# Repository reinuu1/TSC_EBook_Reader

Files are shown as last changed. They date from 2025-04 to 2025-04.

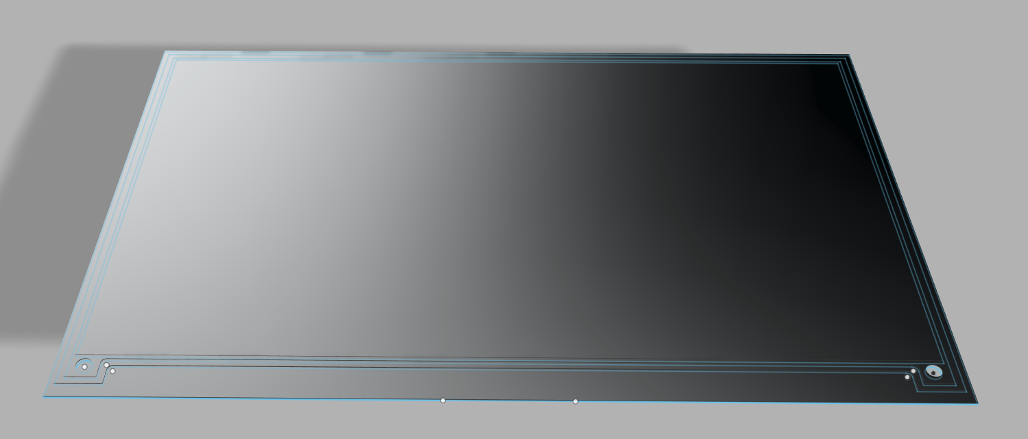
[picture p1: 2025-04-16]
Images/Display.png

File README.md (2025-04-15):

# 📘 TSC_EBook_Reader

## 👨‍💻 Proiect realizat de: DINU Andrei-Marian  
### 📚 Pentru cursul: Teoria Sistemelor de Calcul, 2025  

---

## 🔍 Descriere generală

**OpenBook** este un e-reader open-source, construit în jurul microcontrollerului **ESP32-C6**.  
Acesta dispune de:

- Display **E-Ink 7.5"**
- Baterie **Li-Po**
- Stocare **microSD**
- Senzori de mediu (**BME688**)
- Modul RTC (**DS3231**)

---



## Mapping pini ESP32-C6

| Semnal | ESP32 Pin | Funcție |
|---|---|---|
| EPD_BUSY | IO3 | Status display |
| EPD_RST | IO23 | Reset display |
| EPD_DC | IO5 | Data/Command |
| EPD_CS | IO10 | SPI CS pentru e-paper |
| EPD_CLK | IO6 | SPI Clock |
| EPD_MOSI | IO7 | SPI Data Out |
| SS_SD | IO4 | SD Card CS |
| SD_MISO | IO2 | SPI MISO |
| I2C_SDA | IO21 | RTC + BME688 |
| I2C_SCL | IO22 | RTC + BME688 |
| RTC_RST | IO18 | Reset DS3231 |
| RTC_INT | IO0 | Interrupt RTC |
| 32KHz_CLK | IO1 | Oscilator RTC |
| IO/BOOT Btn | IO9 | Boot |
| IO/CHANGE Btn | IO15 | Navigare |
| RESET | EN | Reset MCU |

## Microcontroller: ESP32-C6-WROOM-1

- **Arhitectură:** RISC-V 32-bit @ 160 MHz  
- **Memorie:** 320KB ROM, 512KB SRAM  
- **Conectivitate:** Wi-Fi 6 (2.4GHz), Bluetooth 5.0  
- **Consum:** ~10mA activ, ~160μA deep sleep  

**Interfețe utilizate:**
- **SPI** – e-paper, microSD, memorie Flash
- **I2C** – RTC, senzor de mediu
- **GPIO** – butoane, LED, semnale control

## 🖥️ Display: Waveshare 7.5" e-Ink V2

- **Rezoluție:** 800x480 px  
- **Interfață:** SPI  
- **Consum:** ~1.2mW activ, ~0.1mW standby

## 🔋 Alimentare

- **Baterie:** Li-Po 1800–2500mAh  
- **Încărcător:** MCP73831  
- **Regulator:** XC6221 LDO 3.3V  

**Protecții integrate:**

- Diodă Schottky – polaritate inversă  
- Varistor ESD – protecție USB  
- Supercapacitor – buffering boot/flash  

**Conectare la ESP32-C6:**

IO7 → MOSI
IO6 → SCK
IO10 → CS
IO5 → DC
IO23 → RST
IO3 → BUSY

## Stocare: MicroSD + SPI Flash
### microSD (până la 32GB FAT32)

IO4 → CS_SD
IO2 → MISO
IO7 → MOSI (partajat)
IO6 → SCK (partajat)
Flash SPI externă (Winbond W25Q64JV – 64Mb)
IO11 → CS
IO2, IO6, IO7 partajați

##  Senzor Mediu: Bosch BME688
- Măsoară: temperatură, umiditate, presiune, compuși gazoși  
- **Consum:** ~3.6mA activ, ~0.1μA sleep  
- **Interfață:** I2C  

**Conectare:**

IO21 → SDA
IO22 → SCL
IO19 → VDDIO (enable senzor)

## RTC: DS3231

- **Precizie:** ±2ppm, compensat termic  
- **Backup:** funcționează pe baterie  
- **Consum:** ~1.5μA backup, ~0.1μA sleep 

**Conectare:**

IO21 → SDA
IO22 → SCL
IO18 → RST
IO0 → INT/SQW
IO1 → 32KHz Clock Out

## ⚡ Estimare consum

| Modul | Activ (mA) | Sleep (μA) |
|---|---|---|
| ESP32-C6 | ~10 | ~160 |
| Display | ~1.2 | ~0.1 |
| microSD | ~50 | ~10 |
| BME688 | ~3.6 | ~0.1 |
| RTC | ~0.0015 | ~0.0001 |
| **Total** | **~65mA**  | **~170μA** |

## Interfață utilizator
- 3 Butoane tactile (TS-1187A):

IO9 → BOOT
IO15 → CHANGE
EN → RESET

- LED status: GPIO + rezistor pull-down  
- Feedback: control simplu via GPIO 

## Alte componente

- **Conector FPC:** Hirose FH34SRJ-24S  
- **Test Pads:** silkscreen pentru depanare  
- **Qwiic/I²C Header:** pentru extensii viitoare 

Observații finale
Toate comunicațiile SPI sunt partajate pe același bus, controlate prin CS separat.

Designul este gândit pentru eficiență energetică și poate funcționa zeci de ore în standby.

Tot sistemul este gândit pentru a fi reproductibil și open-source, ușor de extins cu alte module I²C sau SPI

##  Design Decizii & Trade-offs

-  Alegere ESP32-C6: conectivitate & suport FreeRTOS  
-  E-paper pentru consum redus  
-  Un singur bus SPI (cu CS dedicat pentru SD și e-paper)  
-  GPIO-uri simple pentru butoane

## Debug & Testare

-  Verificare DRC (JLCPCB .dru)  
-  Alimentare testată cu Li-Po + charging  
-  Interfețe SPI & I2C testate cu logic analyzer  
-  Consumul în deep sleep confirmat < 200μA

##  Datasheet-uri & Linkuri componente

| Componentă | Link Datasheet | LINK |
|---|---|---|
| USB Connector 112A-TAAR-R03 | [ESP32-C6-WROOM-1](https://www.attend.com.tw/data/download/file/112A-TAAR-R03_Spec.pdf) | [Status display](https://www.digikey.com/en/products/detail/attend-technology/112A-TAAR-R03/17633923) |
| Inductor 68uH (Würth) | [7.5" V2 e-Paper](https://www.we-online.com/components/products/datasheet/784373170680.pdf) | [Reset display ](https://eu.mouser.com/ProductDetail/Wurth-Elektronik/784373170680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) |
| LED Bridgelux | [DS3231](https://www.bridgelux.com/sites/default/files/resource_media/DS51_Rev%20F%20Bridgelux%20SMD%203030%20Data%20sheet.pdf)  | [Data/Command](https://www.digikey.com/en/products/detail/bridgelux/BXEM-27E0000-0-000/6618599) |
| Voltage Detector BD5229G | [BME688 ](https://fscdn.rohm.com/en/products/databook/datasheet/ic/power/voltage_detector/bd52xxg-e.pdf) | [SPI CS pentru e-paper ](https://www.digikey.com/en/products/detail/rohm-semiconductor/BD5229G-TR/658502) |
| Butoane TL3315 | [XC6221B331MR-G](https://fscdn.rohm.com/en/products/databook/datasheet/ic/power/voltage_detector/bd52xxg-e.pdf) | [SPI Clock ](https://www.digikey.com/en/products/detail/rohm-semiconductor/BD5229G-TR/658502) |
| Supercapacitor 0.011F 3.3V | [MCP73831T-2ACI/OT ](https://mm.digikey.com/Volume0/opasdata/d220001/medias/docus/6537/rev05-CPHCPM.pdf) | [SPI Data Out ](https://www.digikey.com/en/products/detail/seiko-instruments/cph3225a/8692444) |
| RTC DS3231SN | [LP584174 (1800mAh) ](https://www.analog.com/media/en/technical-documentation/data-sheets/DS3231.pdf) | [SD Card CS ](https://www.digikey.com/en/products/detail/analog-devices-inc-maxim-integrated/DS3231SN/1197576) |
| Capacitor 0402YD104MAT2A | [FH34SRJ-24S-0.5SH(50)](https://eu.mouser.com/datasheet/2/40/cx5r_KGM-3223198.pdf) | [SPI MISO ](https://eu.mouser.com/ProductDetail/KYOCERA-AVX/0402YD104MAT2A?qs=4PckX6MNpMErOINbbZj3Cw%3D%3D) |
| ESP32-C6-WROOM-1-N8 | [W25Q64JV ](https://www.espressif.com/sites/default/files/documentation/esp32-c6-wroom-1_wroom-1u_datasheet_en.pdf)  | [RTC + BME688 ](https://www.digikey.com/en/products/detail/espressif-systems/ESP32-C6-WROOM-1-N8/17728866) |
| Varistor USB PFMF.050.2 | [Molex 104031-0811 ](https://ro.mouser.com/datasheet/2/358/typ_PFMF-1275918.pdf) | [RTC + BME688 ](https://ro.mouser.com/ProductDetail/Schurter/PFMF.050.2?qs=1auRipcfynCums5v1iucSA%3D%3D) |
| DiodA Schottky SD0805S020S1R0 | [USB4110-GF-A ](https://datasheets.kyocera-avx.com/schottky.pdf) | [Reset DS3231 ](https://www.digikey.com/en/products/detail/kyocera-avx/sd0805s020s1r0/3749517) |
| Senzor BME680 | [SS14 ](https://www.bosch-sensortec.com/media/boschsensortec/downloads/datasheets/bst-bme680-ds001.pdf) | [ Interrupt RTC  ](https://www.digikey.com/en/products/detail/bosch-sensortec/bme680/7401317) |
| Rezistori SMD 0402 | [PFMF05S050T2 ](https://www.yageo.com/upload/media/product/products/datasheet/rchip/PYu-RC_Group_51_RoHS_L_12.pdf) | [Oscilator RTC ](https://www.digikey.com/en/products/detail/yageo/RC0402JR-07100KL/726416) |
| P-MOS DMG2305UX-7 | [TS-1187A-B-A-B ](https://www.diodes.com/assets/Datasheets/DMG2305UX.pdf) | [Boot ](https://www.digikey.com/en/products/detail/diodes-incorporated/DMG2305UX-7/4340667) |
| MCP73831T (Charger IC) | [RC0402FR-07100KL ](https://ww1.microchip.com/downloads/en/DeviceDoc/MCP73831-Family-Data-Sheet-DS20001984H.pdf) | [Navigare ](https://www.digikey.com/en/products/detail/microchip-technology/MCP73831T-2ACI-OT/964301) |
| Hirose FH34SRJ-24S-0.5SH | [GRM155R61A105KE15D ](https://ro.mouser.com/datasheet/2/185/FH34SRJ_24S_0_5SH_99__CL0580_1255_6_99_2DDrawing_0-1615044.pdf)| [Reset MCU ](https://ro.mouser.com/ProductDetail/Hirose-Connector/FH34SRJ-24S-0.5SH99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) |
| Battery Monitor MAX17048 | https://www.analog.com/media/en/technical-documentation/data-sheets/max17048-max17049.pdf | https://www.digikey.com/en/products/detail/analog-devices-inc-maxim-integrated/MAX17048G-T10/3758921 |
| Diodă MBR0530 | https://ro.mouser.com/datasheet/2/258/MBR0520_MBR0580_SOD123_-2492194.pdf | https://ro.mouser.com/ProductDetail/Micro-Commercial-Components-MCC/MBR0530-TP?qs=KFo7JewZbUECRHkxGanrdg%3D%3D |
| ESD Suppressor – PGB1010603MR | https://www.littelfuse.com/assetdocs/pulseguard-esd-suppressors-pgb1-datasheet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 | https://www.digikey.com/en/products/detail/littelfuse-inc/PGB1010603MR/715755 |
| Qwiic Connector OM-E-QWIIC | https://www.sparkfun.com/qwiic | https://www.digikey.com/en/products/detail/onion-corporation/om-e-qwiic/9922970 |
| Capacitor 0.5pF–100uF GCQ1555C1HR50WB01 | https://ro.mouser.com/datasheet/2/281/1/GCQ1555C1HR50WB01_01A-3146956.pdf | https://ro.mouser.com/ProductDetail/Murata-Electronics/GCQ1555C1HR50WB01D?qs=0lQeLiL1qybSG%2FOlONlvIA%3D%3D |
| USB-C Conector USB4110-GF-A | https://gct.co/files/drawings/usb4110.pdf | https://eu.mouser.com/ProductDetail/GCT/USB4110-GF-A?qs=KUoIvG%2F9IlYiZvIXQjyJeA%3D%3D |
| Rezistor | https://industrial.panasonic.com/ww/products/pt/general-purpose-chip-resistors/models/ERJ2GE0R00X | https://www.digikey.com/en/products/detail/panasonic-electronic-components/ERJ-2GE0R00X/146727 |

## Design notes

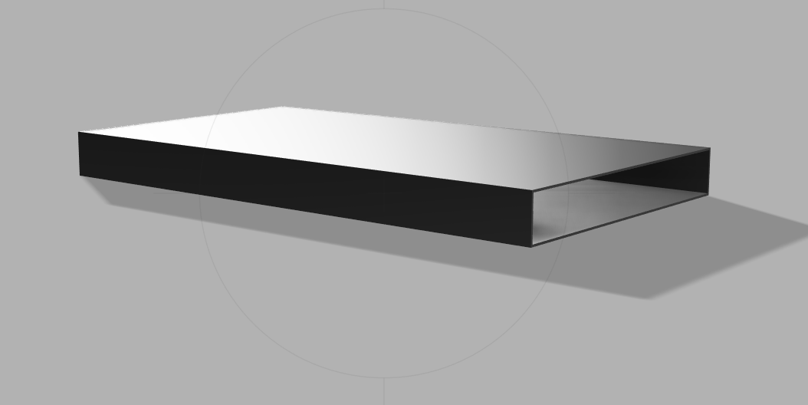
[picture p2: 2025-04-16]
Images/Battery.png

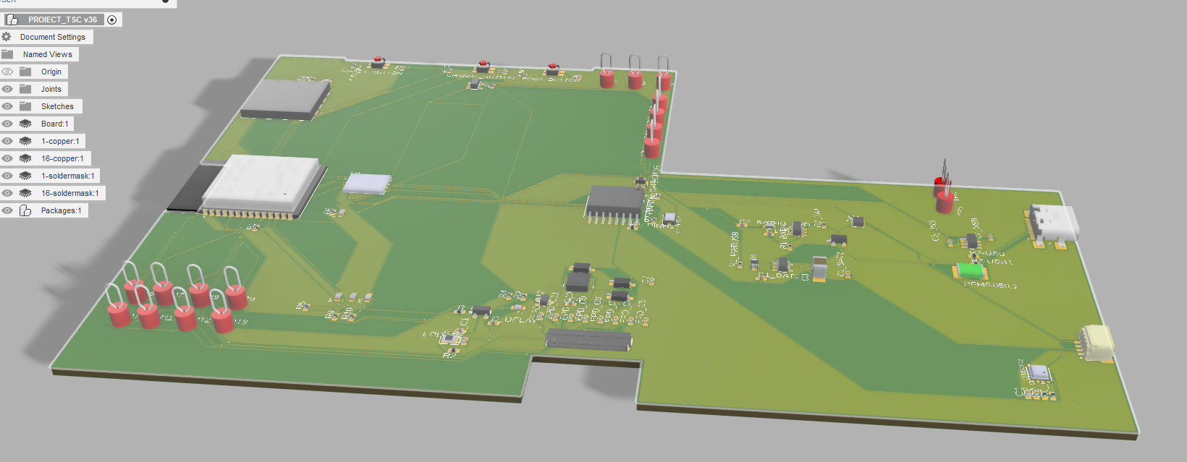
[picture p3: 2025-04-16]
Images/PCB.png

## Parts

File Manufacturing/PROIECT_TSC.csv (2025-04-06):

Qty | Value | Device | Package | Parts | Description | ARROW_PART_NUMBER | ARROW_PRICE-STOCK | AVAILABILITY | CENTROID_NOT_SPECIFIED | CHECK_PRICES | COPYRIGHT | DATASHEET | DESCRIPTION | DIGIKEY_DESCRIPTION | DIGIKEY_PART_NUMBER | HEIGHT | LEAD_FREE | MANUFACTURER_NAME | MANUFACTURER_PART_NUMBER | MF | MFR_NAME | MOUSER_PART_NUMBER | MOUSER_PRICE-STOCK | MOUSER_TESTING_PART_NUMBER | MOUSER_TESTING_PRICE-STOCK | MP | MPN | PACKAGE | POPULARITY | PREFIX | PRICE | PROD_ID | PURCHASE-URL | ROHS | SNAPEDA_LINK | SPICEMODEL | SPICEPREFIX | TEMPERATURE_RANGE_HIGH | TEMPERATURE_RANGE_LOW | TP_SIGNAL_NAME | VALUE
1 |  | ADAFRUIT_LEDCHIP-LED0603 | ADAFRUIT_CHIP-LED0603 | CHG_LED | LED
3 |  | BUTTON_CUSYOMV1 | MYBUTTON | BOOT_BUTTON, CHANGE_BUTTON, RESET_BUTTON
1 |  | ESP32C6_VARISTORCN1812 | ESP32C6_VARISTOR_CT/CN1812 | PFMF.050.1 | VARISTOR |  |  |  |  |  |  |  |  |  |  |  |  |  |  |  |  |  |  |  |  |  |  |  | 0
1 |  | ESP32_WROVER_SPARKFUN-IC-POWER_MCP73831 | ESP32_WROVER_SPARKFUN-IC-POWER_SOT23-5 | MCP73831 | MCP73831T Li-Ion, Li-Pol Controller |  |  |  |  |  |  |  |  |  |  |  |  |  |  |  |  |  |  |  |  |  |  |  |  |  |  | IC-09995
1 |  | SJ | SJ | SJ1 | SMD solder JUMPER |  |  |  |  |  |  |  |  |  |  |  |  |  |  |  |  |  |  |  |  |  |  |  | 3
10 | 0.1uF/50V | EAGLE-LTSPICE_CC0402 | EAGLE-LTSPICE_C0402 | EPD_C1, EPD_C2, EPD_C5, EPD_C6, EPD_C7, EPD_C8, EPD_C9, EPD_C10, EPD_C11, EPD_C12 | CAPACITOR, European symbol |  |  |  |  |  |  |  |  |  |  |  |  |  |  |  |  |  |  |  |  |  |  |  |  |  |  |  |  |  |  | NONE | C
1 | 0.47 | ESP32_WROVER_EAGLE-LTSPICE_RR0402 | ESP32_WROVER_EAGLE-LTSPICE_R0402 | R3 | RESISTOR, European symbol |  |  |  |  |  |  |  |  |  |  |  |  |  |  |  |  |  |  |  |  |  |  |  |  |  |  |  |  |  |  | NONE | R
1 | 100K | ESP32_WROVER_EAGLE-LTSPICE_RR0402 | ESP32_WROVER_EAGLE-LTSPICE_R0402 | R1_PWRUSB | RESISTOR, European symbol |  |  |  |  |  |  |  |  |  |  |  |  |  |  |  |  |  |  |  |  |  |  |  |  |  |  |  |  |  |  | NONE | R
7 | 100nF | EAGLE-LTSPICE_CC0402 | EAGLE-LTSPICE_C0402 | C1, C2, C4_USB, C6, C8, C10, C_DELAY | CAPACITOR, European symbol |  |  |  |  |  |  |  |  |  |  |  |  |  |  |  |  |  |  |  |  |  |  |  |  |  |  |  |  |  |  | NONE | C
1 | 100uF | EAGLE-LTSPICE_CC0402 | EAGLE-LTSPICE_C0402 | C9 | CAPACITOR, European symbol |  |  |  |  |  |  |  |  |  |  |  |  |  |  |  |  |  |  |  |  |  |  |  |  |  |  |  |  |  |  | NONE | C
1 | 100uF TANT | RCL_CPOL-EUCT3528 | RCL_CT3528 | C3 | POLARIZED CAPACITOR, European symbol |  |  |  |  |  |  |  |  |  |  |  |  |  |  |  |  |  |  |  |  |  |  |  | 0 |  |  |  |  |  |  |  | C
16 | 10K | ESP32_WROVER_EAGLE-LTSPICE_RR0402 | ESP32_WROVER_EAGLE-LTSPICE_R0402 | R1, R1_PINH, R1_PINH1, R2-PINH, R2-PINH1, R4, R5, R6, R7, R8, R9, R10, R_BOOT, R_CHANGE, R_CL1, R_RESET | RESISTOR, European symbol |  |  |  |  |  |  |  |  |  |  |  |  |  |  |  |  |  |  |  |  |  |  |  |  |  |  |  |  |  |  | NONE | R
1 | 10uF | EAGLE-LTSPICE_CC0402 | EAGLE-LTSPICE_C0402 | C7 | CAPACITOR, European symbol |  |  |  |  |  |  |  |  |  |  |  |  |  |  |  |  |  |  |  |  |  |  |  |  |  |  |  |  |  |  | NONE | C
1 | 112A-TAAR-R03_ATTEND | 112A-TAAR-R03_ATTEND | 112ATAARR03ATTEND | J4 | Micro SD Card Socket, Push-Push Type, Top Mount, SMT, H=1.83mm, 10u |  |  |  |  |  |  |  | Micro SD Card Socket | Push-Push Type | Top Mount | SMT | H=1.83mm | 10u |  |  | 1.9mm |  | ATTEND | 112A-TAAR-R03 ATTEND
1 | 15 | ESP32_WROVER_EAGLE-LTSPICE_RR0402 | ESP32_WROVER_EAGLE-LTSPICE_R0402 | R_CAPACITOR | RESISTOR, European symbol |  |  |  |  |  |  |  |  |  |  |  |  |  |  |  |  |  |  |  |  |  |  |  |  |  |  |  |  |  |  | NONE | R
1 | 1uF | EAGLE-LTSPICE_CC0402 | EAGLE-LTSPICE_C0402 | C5 | CAPACITOR, European symbol |  |  |  |  |  |  |  |  |  |  |  |  |  |  |  |  |  |  |  |  |  |  |  |  |  |  |  |  |  |  | NONE | C
1 | 2.2 | ESP32_WROVER_EAGLE-LTSPICE_RR0402 | ESP32_WROVER_EAGLE-LTSPICE_R0402 | R2 | RESISTOR, European symbol |  |  |  |  |  |  |  |  |  |  |  |  |  |  |  |  |  |  |  |  |  |  |  |  |  |  |  |  |  |  | NONE | R
1 | 200 | ESP32_WROVER_EAGLE-LTSPICE_RR0402 | ESP32_WROVER_EAGLE-LTSPICE_R0402 | R1_BAT | RESISTOR, European symbol |  |  |  |  |  |  |  |  |  |  |  |  |  |  |  |  |  |  |  |  |  |  |  |  |  |  |  |  |  |  | NONE | R
2 | 20V/4.2A/52mO/1.4W | ESP32_WROVER_SPARKFUN-DISCRETESEMI_MOSFET_PCH-DMG2305UX-7 | ESP32_WROVER_SPARKFUN-DISCRETESEMI_SOT23-3 | Q1, Q2 | P-channel MOSFETs |  |  |  |  |  |  |  |  |  |  |  |  |  |  |  |  |  |  |  |  |  |  |  |  |  |  | TRAN-14388 |  |  |  |  |  |  |  |  | 20V/4.2A/52mO/1.4W
1 | 2K | ESP32_WROVER_EAGLE-LTSPICE_RR0402 | ESP32_WROVER_EAGLE-LTSPICE_R0402 | R2_BAT | RESISTOR, European symbol |  |  |  |  |  |  |  |  |  |  |  |  |  |  |  |  |  |  |  |  |  |  |  |  |  |  |  |  |  |  | NONE | R
5 | 4.7uF | EAGLE-LTSPICE_CC0402 | EAGLE-LTSPICE_C0402 | C1_BAT, C1_BAT1, C1_BAT2, C2_BAT, C5_USB | CAPACITOR, European symbol |  |  |  |  |  |  |  |  |  |  |  |  |  |  |  |  |  |  |  |  |  |  |  |  |  |  |  |  |  |  | NONE | C
1 | 4.7uF/25V | EAGLE-LTSPICE_CC0402 | EAGLE-LTSPICE_C0402 | C4 | CAPACITOR, European symbol |  |  |  |  |  |  |  |  |  |  |  |  |  |  |  |  |  |  |  |  |  |  |  |  |  |  |  |  |  |  | NONE | C
2 | 5k1 | ESP32_WROVER_EAGLE-LTSPICE_RR0402 | ESP32_WROVER_EAGLE-LTSPICE_R0402 | R2-USB, R2-USB1 | RESISTOR, European symbol |  |  |  |  |  |  |  |  |  |  |  |  |  |  |  |  |  |  |  |  |  |  |  |  |  |  |  |  |  |  | NONE | R
1 | 68uH | 744043680IND_4828-WE-TPC_WRE | IND_4828-WE-TPC_WRE | L1 |  |  |  |  |  |  | Copyright (C) 2024 Ultra Librarian. All rights reserved. |  |  |  |  |  |  |  | 744043680 |  | Wurth Electronics
1 | BD5229G-TR | BD5229G-TR | SOT95P280X125-5N | IC1 | Voltage Detector with Adjustable Delay Time: CMOS processes are utilized to develop high precision, low current consumption CMOS reset ICs that allow arbitrary setting of the delay time. The extensive lineup includes both Nch Open Drain and CMOS output types in a wide range of detection voltages (from 2.3V to 6.0V, in 0.1V steps), enabling selection of the ideal solution based on customer requirements. In addition, the entire series is of course both lead-free and RoHS-compliant. |  |  |  |  |  |  |  | Voltage Detector with Adjustable Delay Time: CMOS processes are utilized to develop high precision | low current consumption CMOS reset ICs that allow arbitrary setting of the delay time. The extensive lineup includes both Nch Open Drain and CMOS output types in a wide range of detection voltages (from 2.3V to 6.0V | in 0.1V steps) | enabling selection of the ideal solution based on customer requirements. In addition | the entire series is of course both lead-free and RoHS-compliant. |  |  | 1.25mm |  | ROHM Semiconductor | BD5229G-TR |  |  | 755-BD5229G-TR | https://www.mouser.co.uk/ProductDetail/ROHM-Semiconductor/BD5229G-TR?qs=4kLU8WoGk0vvnhrrYwdszw%3D%3D
1 | BME688 | ESP32_WROVER_BME680_BME680 | ESP32_WROVER_BME680_PSON80P300X300X100-8N | SENSOR2 | Integrated Environmental Unit |  |  | Unavailable |  |  |  |  | Integrated Environmental Unit |  |  |  |  |  |  | Bosch Sensortec |  |  |  |  |  | BME680 |  | LGA-8 Bosch Tools |  |  | None
1 | CPH3225A | CPH3225A | CAPCP3225X100N | C10_SUPERCAP | Cap 0.011F 3.3V 1210 Flat Check availability |  |  | Not in stock |  | https://www.snapeda.com/parts/CPH3225A/Seiko+Instruments/view-part/?ref=eda |  |  | 11 mF (EDLC) Supercapacitor 3.3 V 1210 (3225 Metric) - - |  |  |  |  |  |  | Seiko Instruments |  |  |  |  |  | CPH3225A |  | 1210 Seiko |  |  | None |  | https://www.snapeda.com/api/url_track_click_mouser/?unipart_id=562593&manufacturer=Seiko Instruments&part_name=CPH3225A&search_term=None |  | https://www.snapeda.com/parts/CPH3225A/Seiko+Instruments/view-part/?ref=snap
1 | DS3231SN# | DS3231SN# | SOIC127P1032X265-16N | U3 | Real Time Clock Serial 16-Pin SOIC W T/R Check availability |  |  | In Stock |  | https://www.snapeda.com/parts/DS3231SN%23/Analog+Devices/view-part/?ref=eda |  |  | Extremely Accurate I²C-Integrated RTC/TCXO/Crystal |  |  |  |  |  |  | Analog Devices |  |  |  |  |  | DS3231SN# |  | SOIC-16 Maxim |  |  | None |  | https://www.snapeda.com/api/url_track_click_mouser/?unipart_id=99048&manufacturer=Analog Devices&part_name=DS3231SN#&search_term=None |  | https://www.snapeda.com/parts/DS3231SN%23/Analog+Devices/view-part/?ref=snap
1 | ESP32-C6-WROOM-1-N8 | ESP32-C6-WROOM-1-N8 | XCVR_ESP32-C6-WROOM-1-N8 | U2 | Check availability |  |  | In Stock |  | https://www.snapeda.com/parts/ESP32-C6-WROOM-1-N8/Espressif+Systems/view-part/?ref=eda |  |  | Multiprotocol Modules ESP32-C6 module | Wi-Fi 6 in 2.4 GHz band | Bluetooth 5 | Zigbee 3.0 and Thread. ESP34-WROOM Compatible - ENGINEERING SAMPLE |  |  |  |  |  |  | Espressif Systems |  |  |  |  |  | ESP32-C6-WROOM-1-N8 |  | None |  |  | None |  |  |  | https://www.snapeda.com/parts/ESP32-C6-WROOM-1-N8/Espressif+Systems/view-part/?ref=snap
2 | ESP32_WROVER_AVX---SD0805S020S1R0_AVX_SD0805S020S1R0_0_0AVX_SD0805S020S1R0_0_0 | ESP32_WROVER_AVX---SD0805S020S1R0_AVX_SD0805S020S1R0_0_0AVX_SD0805S020S1R0_0_0 | ESP32_WROVER_AVX---SD0805S020S1R0_AVX_SD0805S020S1R0_0 | D2, D7 | Schottky Barrier Rectifier Diode |  |  |  | No |  |  | http://datasheets.avx.com/schottky.pdf |  | DIODE SCHOTTKY 20V 1A 0805 | 478-7800-1-ND |  | yes |  |  | AVX |  | 581-SD0805S020S1R0 |  |  |  |  |  | 0805 (2012 metric) |  | D |  |  |  | yes |  |  |  | +125°C | -55°C
1 | FH34SRJ-24S-0.5SH_99_ | FH34SRJ-24S-0.5SH_99_ | FH34SRJ24S05SH99 | J1 | (0.50mm) Surface Mount, Right Angle |  |  |  |  |  |  |  | 24 Position FFC | FPC Connector Contacts | (0.50mm) Surface Mount | Right Angle |  |  | 1.1mm |  | Hirose | FH34SRJ-24S-0.5SH(99) |  |  | 798-FH34SRJ24S05SH99 | https://www.mouser.co.uk/ProductDetail/Hirose-Connector/FH34SRJ-24S-0.5SH99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
1 | J2 | SAMACSYS_PARTS_USB4110-GF-A | SAMACSYS_PARTS_USB4110GFA | J2 | CONN USB 2.0 TYPE-C R/A SMT |  |  |  |  |  |  |  | CONN USB 2.0 TYPE-C R/A SMT |  |  | 3.26mm |  | GCT (GLOBAL CONNECTOR TECHNOLOGY) | USB4110-GF-A |  |  | 640-USB4110-GF-A | https://www.mouser.co.uk/ProductDetail/GCT/USB4110-GF-A?qs=KUoIvG%2F9IlYiZvIXQjyJeA%3D%3D
1 | MAX17048G+T10 | MAX17048G+T10 | SON50P200X200X80-9N | U4 | Check availability |  |  | In Stock |  | https://www.snapeda.com/parts/MAX17048G+T10/Analog+Devices/view-part/?ref=eda |  |  | 3µA 1-Cell/2-Cell Fuel Gauge with ModelGauge |  |  |  |  |  |  | Analog Devices |  |  |  |  |  | MAX17048G+T10 |  | TDFN-8 Maxim |  |  | None |  | https://www.snapeda.com/api/url_track_click_mouser/?unipart_id=329239&manufacturer=Analog Devices&part_name=MAX17048G+T10&search_term=None |  | https://www.snapeda.com/parts/MAX17048G+T10/Analog+Devices/view-part/?ref=snap
3 | MBR0530 | MBR0530 | SOD3716X135N | D3, D4, D5 | ON SEMICONDUCTOR - MBR0530 - DIODE, SCHOTTKY, 0.5A, 30V, SOD-123 |  |  | In Stock |  | https://www.snapeda.com/parts/MBR0530/Onsemi/view-part/?ref=eda |  |  | Diode Schottky 30 V 500mA Surface Mount SOD-123 |  |  |  |  |  |  | ON Semiconductor |  |  |  |  |  | MBR0530 |  | SOD-123-2 ON Semiconductor |  |  | None |  | https://www.snapeda.com/api/url_track_click_mouser/?unipart_id=179458&manufacturer=ON Semiconductor&part_name=MBR0530&search_term=None |  | https://www.snapeda.com/parts/MBR0530/Onsemi/view-part/?ref=snap
6 | PGB1010603MR | PGB1010603MR | DIOC1608X36N | D6, D8, D9, D10, D11, D12 | Check availability |  |  | In Stock |  | https://www.snapeda.com/parts/PGB1010603MR/Littelfuse/view-part/?ref=eda |  |  | 150V (Typ) Clamp - Ipp Tvs Diode Surface Mount 0603 (1608 Metric) |  |  |  |  |  |  | Littelfuse Inc. |  |  |  |  |  | PGB1010603MR |  | 0603 Littelfuse Inc. |  |  | None |  | https://www.snapeda.com/api/url_track_click_mouser/?unipart_id=5659453&manufacturer=Littelfuse Inc.&part_name=PGB1010603MR&search_term=None |  | https://www.snapeda.com/parts/PGB1010603MR/Littelfuse/view-part/?ref=snap
1 | QWIIC_RIGHT_ANGLE | QWIIC_CONNECTORJS-1MM | JST04_1MM_RA | J3 | SparkFun I2C Standard Qwiic Connector |  |  |  |  |  |  |  |  |  |  |  |  |  |  |  |  |  |  |  |  |  |  |  |  |  |  | CONN-13694 |  |  |  |  |  |  |  |  | QWIIC_RIGHT_ANGLE
1 | SI1308EDL-T1-GE3 | SI1308EDL-T1-GE3 | SOT65P210X110-3N | Q3 | MOSFET N-Ch 30V 1.5A TrenchFET SC70 Vishay Si1308EDL-T1-GE3 N-channel MOSFET Transistor, 1.5 A, 30 V, 3-Pin SC-70 |  |  | In Stock |  | https://www.snapeda.com/parts/SI1308EDL-T1-GE3/Vishay+Siliconix/view-part/?ref=eda |  |  | Si1308EDL-T1-GE3 N-channel MOSFET Transistor | 1.5 A | 30 V | 3-Pin SC-70 | Siliconix / Vishay SI1308EDL-T1-GE3 |  |  |  |  |  |  | Vishay Siliconix |  |  |  |  |  | SI1308EDL-T1-GE3 |  | SOT-323 Vishay Semiconductor |  |  | None |  | https://www.snapeda.com/api/url_track_click_mouser/?unipart_id=274603&manufacturer=Vishay Siliconix&part_name=SI1308EDL-T1-GE3&search_term=None |  | https://www.snapeda.com/parts/SI1308EDL-T1-GE3/Vishay+Siliconix/view-part/?ref=snap
17 | TPTP20R | TPTP20R | TP20R | TP1, TP2, TP3, TP4, TP5, TP6, TP7, TP8, TP9, TP10, TP11, TP12, TP13, TP14, TP15, TP16, TP17 | Test pad |  |  |  |  |  |  |  |  |  |  |  |  |  |  |  |  |  |  |  |  |  |  |  | 2
1 | USBLC6-2SC6Y | USBLC6-2SC6Y | SOT95P280X145-6N | D1 | Low Cap. ESD Protection Auto SOT-23-6 STMicroelectronics USBLC6-2SC6Y, Dual Uni-Directional TVS Diode Array, 6-Pin SOT-23 |  |  | In Stock |  | https://www.snapeda.com/parts/USBLC6-2SC6Y/STMicroelectronics/view-part/?ref=eda |  |  | 17V Clamp 5A (8/20µs) Ipp Tvs Diode Surface Mount SOT-23-6 |  |  |  |  |  |  | STMicroelectronics |  |  |  |  |  | USBLC6-2SC6Y |  | SOT-23-6 STMicroelectronics |  |  | None |  |  |  | https://www.snapeda.com/parts/USBLC6-2SC6Y/STMicroelectronics/view-part/?ref=snap
1 | W25Q512JVEIQ | W25Q512JVEIQ | SON127P600X800X80-9N | U1 | Check availability |  |  | In Stock |  | https://www.snapeda.com/parts/W25Q512JVEIQ/Winbond+Electronics/view-part/?ref=eda |  |  | FLASH - NOR Memory IC 512Mb (64M x 8) SPI - Quad I/O 133 MHz 8-WSON (8x6) |  |  |  |  |  |  | Winbond Electronics |  |  |  |  |  | W25Q512JVEIQ |  | Package |  |  | None |  |  |  | https://www.snapeda.com/parts/W25Q512JVEIQ/Winbond+Electronics/view-part/?ref=snap
1 | XC6220A331MR-G | XC6220A331MR-G | SOT95P280X120-5N | IC4 | LDO Voltage Regulators |  |  |  |  |  |  |  | LDO Voltage Regulators |  |  | 1.2mm |  | Torex | XC6220A331MR-G |  |  | 865-XC6220A331MR-G | https://www.mouser.co.uk/ProductDetail/Torex-Semiconductor/XC6220A331MR-G?qs=AsjdqWjXhJ8ZSWznL1J0gg%3D%3D

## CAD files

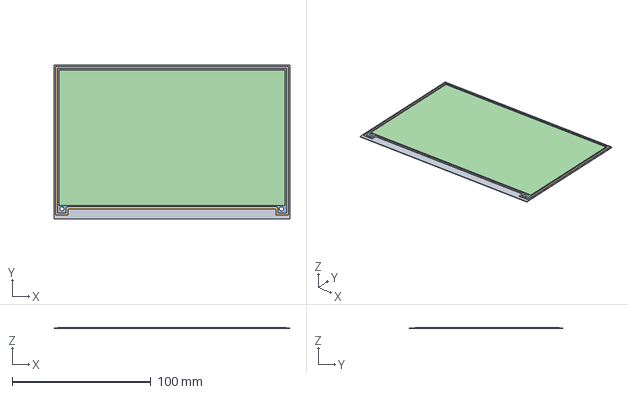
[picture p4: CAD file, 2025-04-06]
Mechanical/ePaper_7.5inch_V2 v6.step
170.2 x 111.2 x 0.85 mm

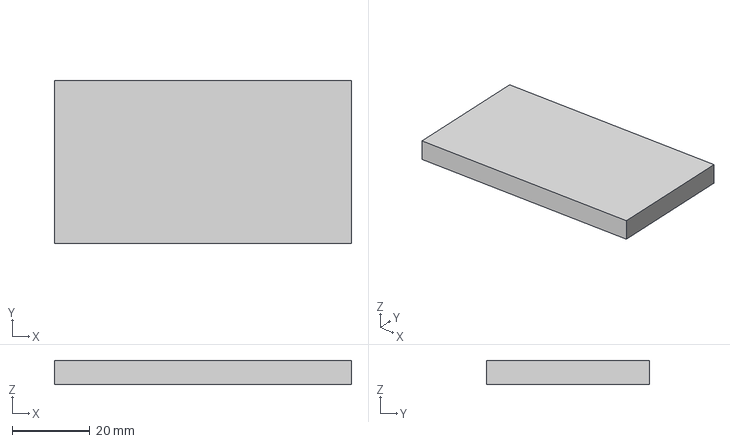
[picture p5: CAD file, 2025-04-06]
Mechanical/Lithium-Ion Battery v2.step
76.5 x 42.0 x 6.30 mm

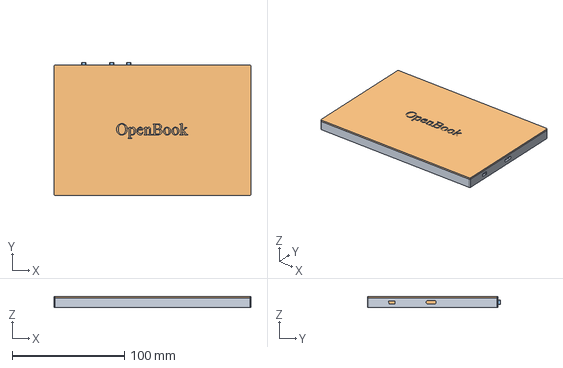
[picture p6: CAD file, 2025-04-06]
Mechanical/CARCASA v1.step
175.2 x 118.5 x 10.2 mm

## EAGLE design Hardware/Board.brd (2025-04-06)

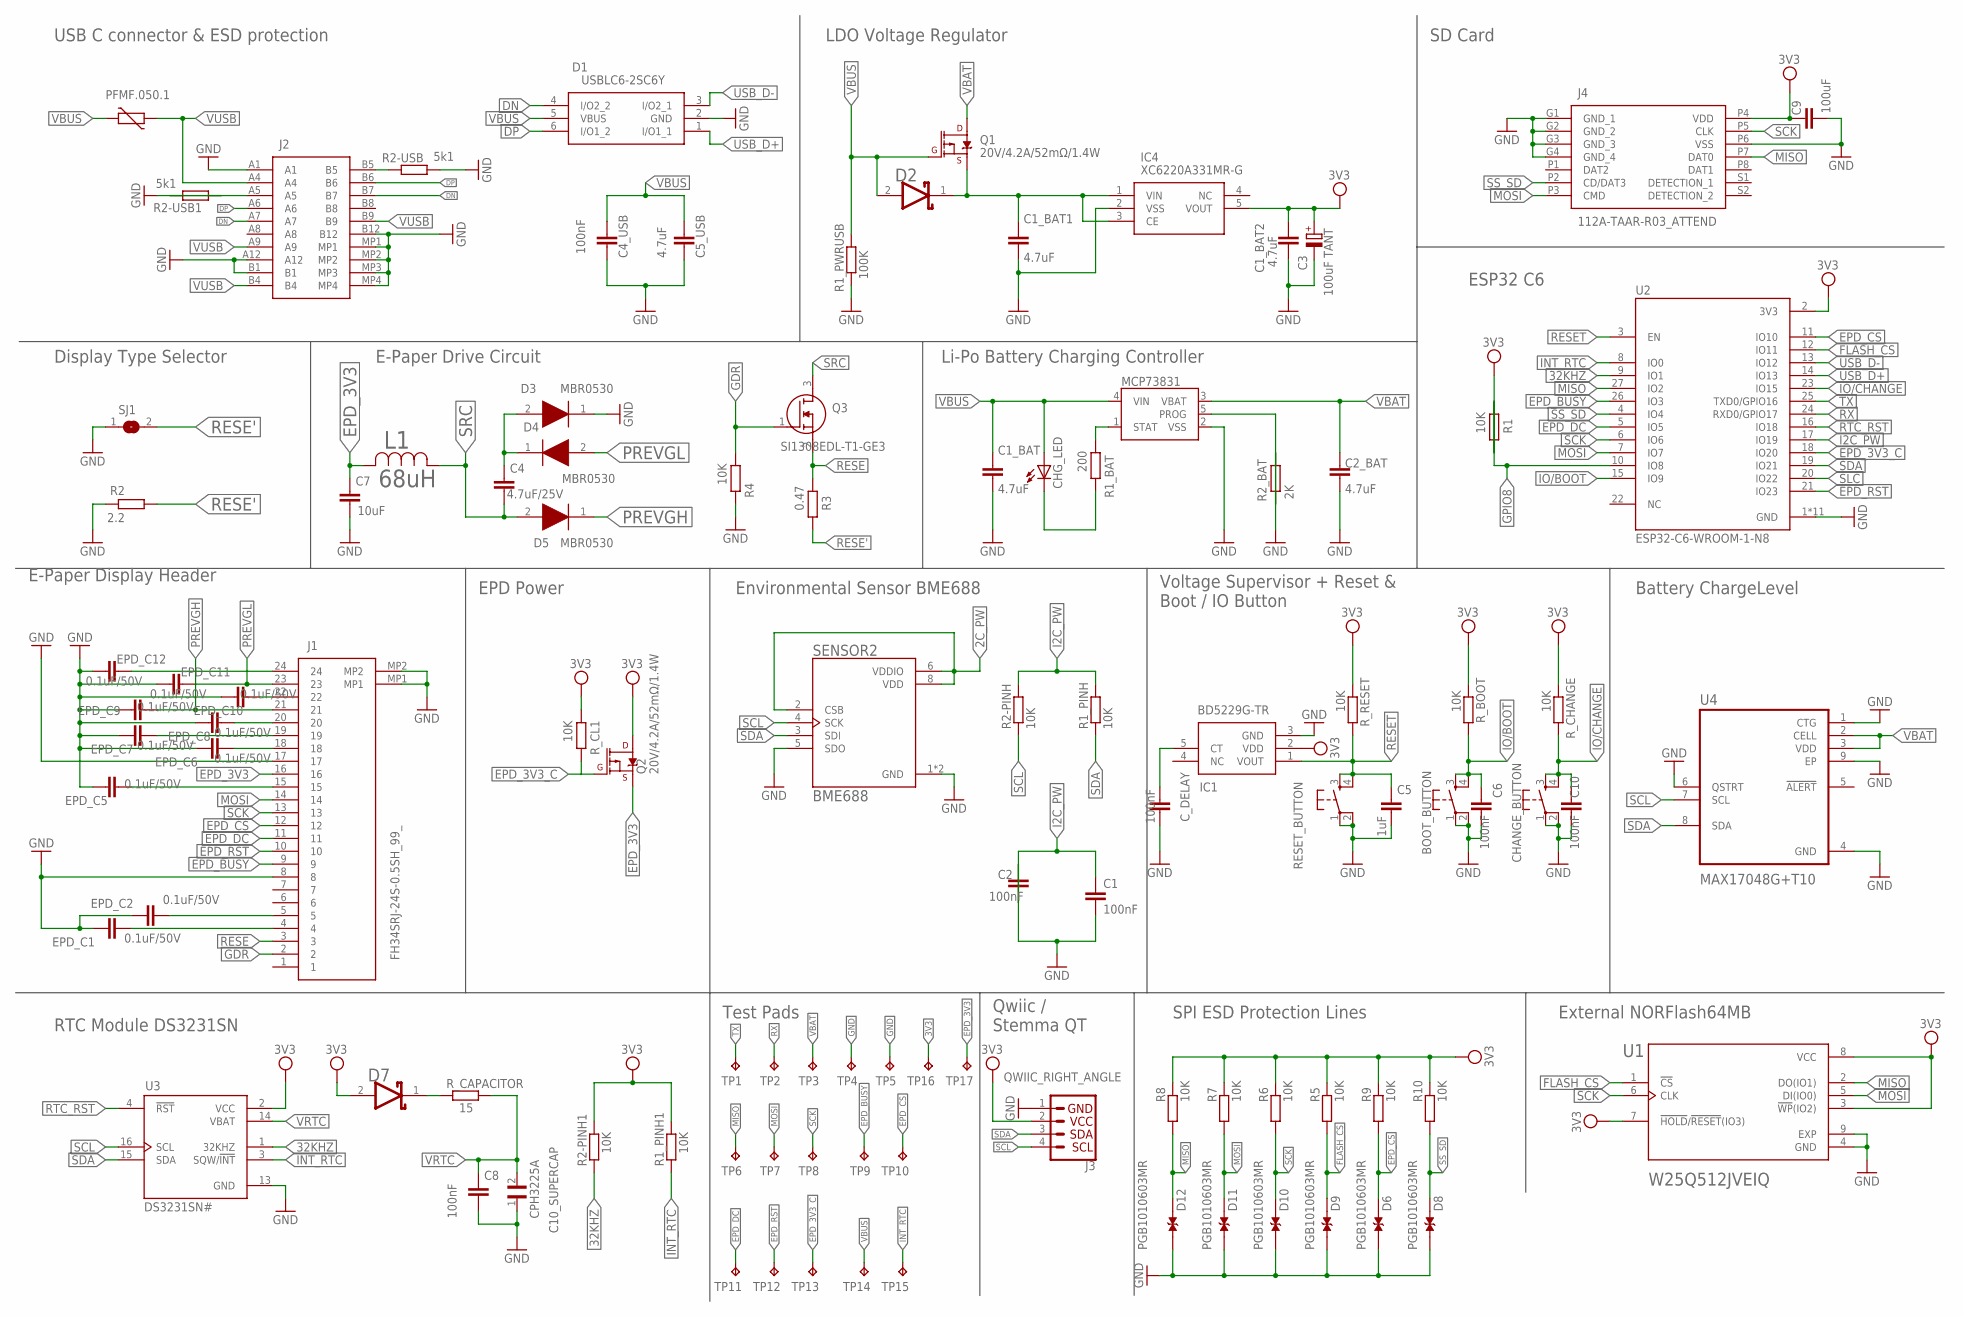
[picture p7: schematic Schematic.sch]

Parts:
BOOT_BUTTON: BUTTON_CUSYOMV1; MYBUTTON
C1, C2, C4_USB, C6, C8, C10: 100nF; EAGLE-LTSPICE_C0402
C1_BAT, C1_BAT1, C1_BAT2, C2_BAT, C5_USB: 4.7uF; EAGLE-LTSPICE_C0402
C3: 100uF TANT; RCL_CT3528
C4: 4.7uF/25V; EAGLE-LTSPICE_C0402
C5: 1uF; EAGLE-LTSPICE_C0402
C7: 10uF; EAGLE-LTSPICE_C0402
C9: 100uF; EAGLE-LTSPICE_C0402
C10_SUPERCAP: CPH3225A; CAPCP3225X100N
CHANGE_BUTTON: BUTTON_CUSYOMV1; MYBUTTON
CHG_LED: ADAFRUIT_LEDCHIP-LED0603; ADAFRUIT_CHIP-LED0603
C_DELAY: 100nF; EAGLE-LTSPICE_C0402
D1: USBLC6-2SC6Y; SOT95P280X145-6N
D2, D7: ESP32_WROVER_AVX---SD0805S020S1R0_AVX_SD0805S020S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; ESP32_WROVER_AVX---SD0805S020S1R0_AVX_SD0805S020S1R0_0
D3, D4, D5: MBR0530; SOD3716X135N
D6, D8, D9, D10, D11, D12: PGB1010603MR; DIOC1608X36N
EPD_C1, EPD_C2, EPD_C5, EPD_C6, EPD_C7, EPD_C8, EPD_C9, EPD_C10, EPD_C11, EPD_C12: 0.1uF/50V; EAGLE-LTSPICE_C0402
IC1: BD5229G-TR; SOT95P280X125-5N
IC4: XC6220A331MR-G; SOT95P280X120-5N
J1: FH34SRJ-24S-0.5SH_99_; FH34SRJ24S05SH99
J2: J2; SAMACSYS_PARTS_USB4110GFA
J3: QWIIC_RIGHT_ANGLE; JST04_1MM_RA
J4: 112A-TAAR-R03_ATTEND; 112ATAARR03ATTEND
L1: 68uH; IND_4828-WE-TPC_WRE
MCP73831: ESP32_WROVER_SPARKFUN-IC-POWER_MCP73831; ESP32_WROVER_SPARKFUN-IC-POWER_SOT23-5
PFMF.050.1: ESP32C6_VARISTORCN1812; ESP32C6_VARISTOR_CT/CN1812
Q1, Q2: 20V/4.2A/52mΩ/1.4W; ESP32_WROVER_SPARKFUN-DISCRETESEMI_SOT23-3
Q3: SI1308EDL-T1-GE3; SOT65P210X110-3N
R1, R1_PINH, R1_PINH1, R2-PINH, R2-PINH1, R4, R5, R6, R7, R8, R9, R10: 10K; ESP32_WROVER_EAGLE-LTSPICE_R0402
R1_BAT: 200; ESP32_WROVER_EAGLE-LTSPICE_R0402
R1_PWRUSB: 100K; ESP32_WROVER_EAGLE-LTSPICE_R0402
R2: 2.2; ESP32_WROVER_EAGLE-LTSPICE_R0402
R2-USB, R2-USB1: 5k1; ESP32_WROVER_EAGLE-LTSPICE_R0402
R2_BAT: 2K; ESP32_WROVER_EAGLE-LTSPICE_R0402
R3: 0.47; ESP32_WROVER_EAGLE-LTSPICE_R0402
RESET_BUTTON: BUTTON_CUSYOMV1; MYBUTTON
R_BOOT: 10K; ESP32_WROVER_EAGLE-LTSPICE_R0402
R_CAPACITOR: 15; ESP32_WROVER_EAGLE-LTSPICE_R0402
R_CHANGE: 10K; ESP32_WROVER_EAGLE-LTSPICE_R0402
R_CL1: 10K; ESP32_WROVER_EAGLE-LTSPICE_R0402
R_RESET: 10K; ESP32_WROVER_EAGLE-LTSPICE_R0402
SENSOR2: BME688; ESP32_WROVER_BME680_PSON80P300X300X100-8N
SJ1: SJ
TP1, TP2, TP3, TP4, TP5, TP6, TP7, TP8, TP9, TP10, TP11, TP12, TP13, TP14, TP15, TP16, TP17: TPTP20R; TP20R
U1: W25Q512JVEIQ; SON127P600X800X80-9N
U2: ESP32-C6-WROOM-1-N8; XCVR_ESP32-C6-WROOM-1-N8
U3: DS3231SN#; SOIC127P1032X265-16N
U4: MAX17048G+T10; SON50P200X200X80-9N

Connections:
2C_PW: SENSOR2.2 (CSB), SENSOR2.6 (VDDIO), SENSOR2.8 (VDD)
3V3: C1_BAT2.2, C3.+, C9.2, D7.2 (ANODE), IC1.2 (VDD), IC4.5 (VOUT), J3.2, J4.P4 (VDD), Q2.3 (D), R1.1, R1_PINH1.2, R2-PINH1.2, R5.2, R6.2, R7.2, R8.2, R9.2, R10.2, R_BOOT.1, R_CHANGE.1, R_CL1.2, R_RESET.1, TP16.TP, U1.3 (!WP!(IO2)), U1.7 (!HOLD!/!RESET!(IO3)), U1.8 (VCC), U2.2 (3V3), U3.2 (VCC)
32KHZ: R2-PINH1.1, U2.9 (IO1), U3.1 (32KHZ)
DN: J2.A7
DP: J2.A6
EPD_3V3: C7.1, J1.16, L1.2, Q2.2 (S), TP17.TP
EPD_3V3_C: Q2.1 (G), R_CL1.1, TP13.TP, U2.18 (IO20)
EPD_BUSY: J1.9, TP9.TP, U2.26 (IO3)
EPD_CS: D6.2, J1.12, R9.1, TP10.TP, U2.11 (IO10)
EPD_DC: J1.11, TP11.TP, U2.5 (IO5)
EPD_RST: J1.10, TP12.TP, U2.21 (IO23)
FLASH_CS: D9.2, R5.1, U1.1 (!CS), U2.12 (IO11)
GDR: J1.2, Q3.1 (G), R4.2
GND: BOOT_BUTTON.1, BOOT_BUTTON.2, C1.2, C1_BAT.1, C1_BAT1.1, C1_BAT2.1, C2.2, C2_BAT.1, C3.-, C4_USB.2, C5.2, C5_USB.2, C6.2, C7.2, C8.2, C9.1, C10.2, C10_SUPERCAP.1, CHANGE_BUTTON.1, CHANGE_BUTTON.2, C_DELAY.2, D1.2 (GND), D3.1 (K), D6.1, D8.1, D9.1, D10.1, D11.1, D12.1, EPD_C1.1, EPD_C2.1, EPD_C5.1, EPD_C6.1, EPD_C7.1, EPD_C8.1, EPD_C9.1, EPD_C10.1, EPD_C11.1, EPD_C12.1, IC1.3 (GND), IC4.2 (VSS), J1.8, J1.17, J1.MP1, J1.MP2, J2.A1, J2.A12, J2.B1, J2.B12, J2.MP1, J2.MP2, J2.MP3, J2.MP4, J3.1, J4.G1 (GND_1), J4.G2 (GND_2), J4.G3 (GND_3), J4.G4 (GND_4), J4.P6 (VSS), MCP73831.2 (VSS), R1_PWRUSB.1, R2.2, R2-USB.2, R2-USB1.1, R2_BAT.1, R4.1, RESET_BUTTON.1, RESET_BUTTON.2, SENSOR2.1 (GND), SENSOR2.5 (SDO), SENSOR2.7 (GND), SJ1.1, TP4.TP, TP5.TP, U1.4 (GND), U1.9 (EXP), U2.1 (GND), U2.28 (GND), U2.29_1 (GND), U2.29_2 (GND), U2.29_3 (GND), U2.29_4 (GND), U2.29_5 (GND), U2.29_6 (GND), U2.29_7 (GND), U2.29_8 (GND), U2.29_9 (GND), U3.13 (GND), U4.1 (CTG), U4.4 (GND), U4.6 (QSTRT), U4.9 (EP)
GPIO8: R1.2, U2.10 (IO8)
I2C_PW: R1_PINH.2, R2-PINH.2, U2.17 (IO19)
INT_RTC: R1_PINH1.1, TP15.TP, U2.8 (IO0), U3.3 (SQW/!INT)
IO/BOOT: BOOT_BUTTON.3, BOOT_BUTTON.4, C6.1, R_BOOT.2, U2.15 (IO9)
IO/CHANGE: C10.1, CHANGE_BUTTON.3, CHANGE_BUTTON.4, R_CHANGE.2, U2.23 (IO15)
MISO: D12.2, J4.P7 (DAT0), R8.1, TP6.TP, U1.2 (DO(IO1)), U2.27 (IO2)
MOSI: D11.2, J1.14, J4.P3 (CMD), R7.1, TP7.TP, U1.5 (DI(IO0)), U2.7 (IO7)
unnamed: J2.A5, R2-USB1.2
unnamed: J2.B5, R2-USB.1
unnamed: C4_USB.1, C5_USB.1
unnamed: C4.1, D3.2 (A), D4.1 (K)
unnamed: MCP73831.1 (STAT), R1_BAT.2
unnamed: C1_BAT1.2, D2.1 (CATHODE), IC4.1 (VIN), IC4.3 (CE), Q1.2 (S)
unnamed: CHG_LED.C, R1_BAT.1
unnamed: EPD_C12.2, J1.24
unnamed: MCP73831.5 (PROG), R2_BAT.2
unnamed: C1.1, C2.1
unnamed: C_DELAY.1, IC1.5 (CT)
unnamed: D7.1 (CATHODE), R_CAPACITOR.1
unnamed: EPD_C10.2, J1.22
unnamed: EPD_C8.2, J1.20
unnamed: EPD_C7.2, J1.19
unnamed: EPD_C6.2, J1.18
unnamed: EPD_C5.2, J1.15
unnamed: EPD_C2.2, J1.5
unnamed: EPD_C1.2, J1.4
PREVGH: D5.1 (K), EPD_C9.2, J1.21
PREVGL: D4.2 (A), EPD_C11.2, J1.23
RESE: J1.3, Q3.2 (S), R3.2
RESE': R3.1, SJ1.2
RESET: C5.1, IC1.1 (VOUT), RESET_BUTTON.3, RESET_BUTTON.4, R_RESET.2, U2.3 (EN)
RTC_RST: U2.16 (IO18), U3.4 (!RST)
RX: TP2.TP, U2.24 (RXD0/GPIO17)
SCK: D10.2, J1.13, J4.P5 (CLK), R6.1, TP8.TP, U1.6 (CLK), U2.6 (IO6)
SCL: J3.4, R2-PINH.1, SENSOR2.4 (SCK), U3.16 (SCL), U4.7 (SCL)
SDA: J3.3, R1_PINH.1, SENSOR2.3 (SDI), U2.19 (IO21), U3.15 (SDA), U4.8 (SDA)
SLC: U2.20 (IO22)
SRC: C4.2, D5.2 (A), L1.1, Q3.3 (D)
SS_SD: D8.2, J4.P2 (CD/DAT3), R10.1, U2.4 (IO4)
TX: TP1.TP, U2.25 (TXD0/GPIO16)
USB_D+: D1.1 (I/O1_1), U2.14 (IO13)
USB_D-: D1.3 (I/O2_1), U2.13 (IO12)
VBAT: C2_BAT.2, MCP73831.3 (VBAT), Q1.3 (D), TP3.TP, U4.2 (CELL), U4.3 (VDD)
VBUS: C1_BAT.2, CHG_LED.A, D2.2 (ANODE), MCP73831.4 (VIN), PFMF.050.1.2, Q1.1 (G), R1_PWRUSB.2, TP14.TP
VRTC: C8.1, C10_SUPERCAP.2, R_CAPACITOR.2, U3.14 (VBAT)
VUSB: J2.A4, PFMF.050.1.1

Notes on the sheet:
USB C connector & ESD protection
Display Type Selector
E-Paper Drive Circuit
LDO Voltage Regulator
SD Card
Li-Po Battery Charging Controller
ESP32 C6
E-Paper Display Header
EPD Power
Environmental Sensor BME688
Voltage Supervisor + Reset & Boot / IO Button
Battery ChargeLevel
External NORFlash64MB
RTC Module DS3231SN
Test Pads
Qwiic / Stemma QT
SPI ESD Protection Lines

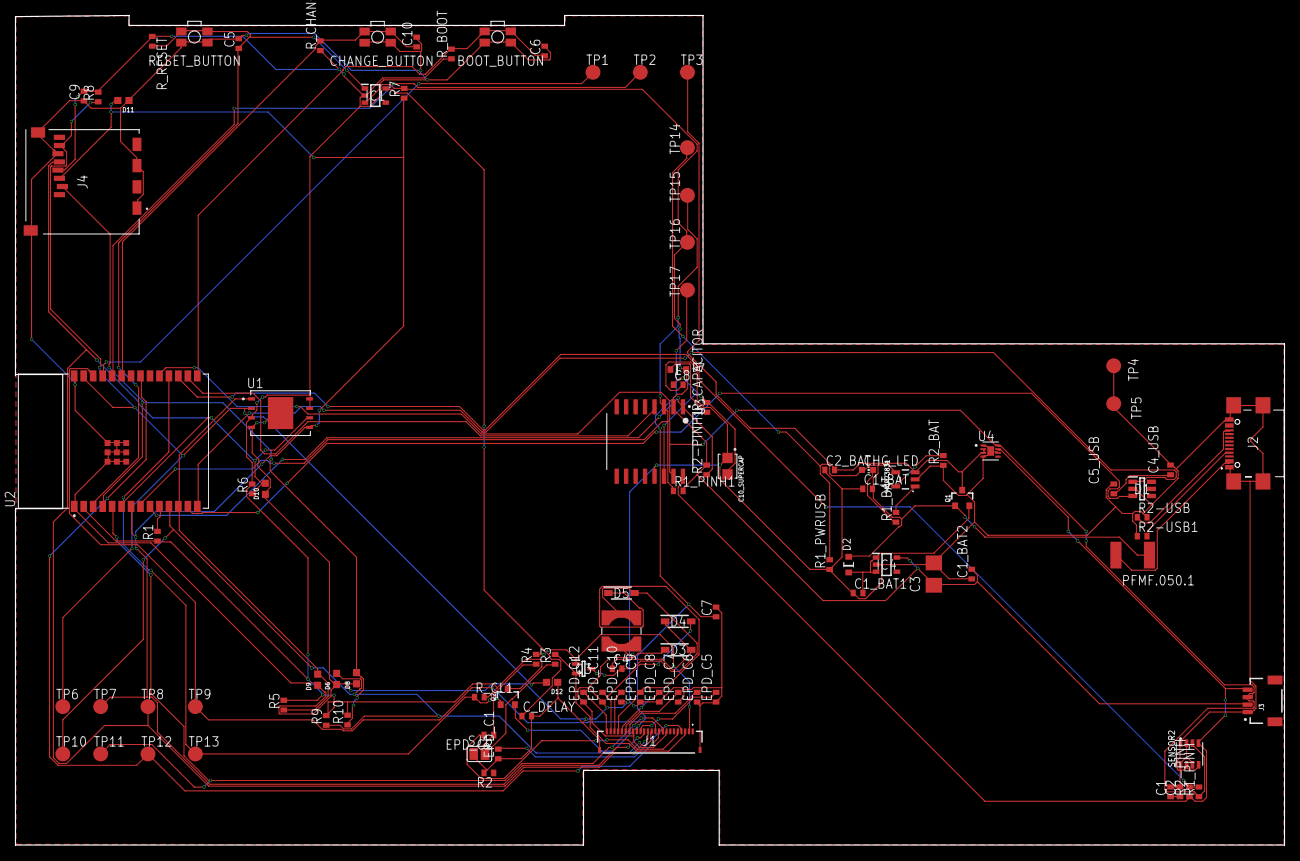
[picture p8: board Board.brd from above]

Board: 2 copper layers, 170.2 x 111.3 mm, 103 parts (0 on the bottom side), 57 nets.

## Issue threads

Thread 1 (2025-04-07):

Schematic review

Grizzlly, 2025-04-07:
The schematic is mostly clean, however, there is something weird with how you connect your wires.

These are the issues that I found:

- [ ] Missing junction in net EPD_3V3_C
- [ ] Unconnected wires and overlapping pins
- [ ] Approve other specific warnings

Overall, very good job!

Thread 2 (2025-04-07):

Board review

Grizzlly, 2025-04-07:
The PCB looks very good, and everything is wired correctly.

These are some suggestions to make it even better!

Overall, it looks great!

Closed 2025-04-15.

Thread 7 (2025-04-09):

Re-route with higher copper width to take into account fabrication errors.

Grizzlly, 2025-04-09:
All your wires have been routed using a width of 0.127mm contrary to project specs/requirements.

All wires should have a minimum width of 0.15mm with power routes being 0.3mm.

Closed 2025-04-15.

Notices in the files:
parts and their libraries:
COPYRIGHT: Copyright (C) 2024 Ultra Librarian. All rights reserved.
